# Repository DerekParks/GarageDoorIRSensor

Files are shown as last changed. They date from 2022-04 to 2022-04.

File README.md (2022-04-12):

# Garage Door IR Sensor

This is a little garage door state sensor based on Sharp IR sensors, an ADS1115, & an ESP-01. I originally planned to hack this together with parts I had around in an afternoon. Two months later, here were are. 😉 

The boards were made for a CT clamp current sensor but work great for reading in any voltage from 0-3.3v.

 A schematic is below. The IR sensors hook up to ports 3  & 4 of the ADS1115.
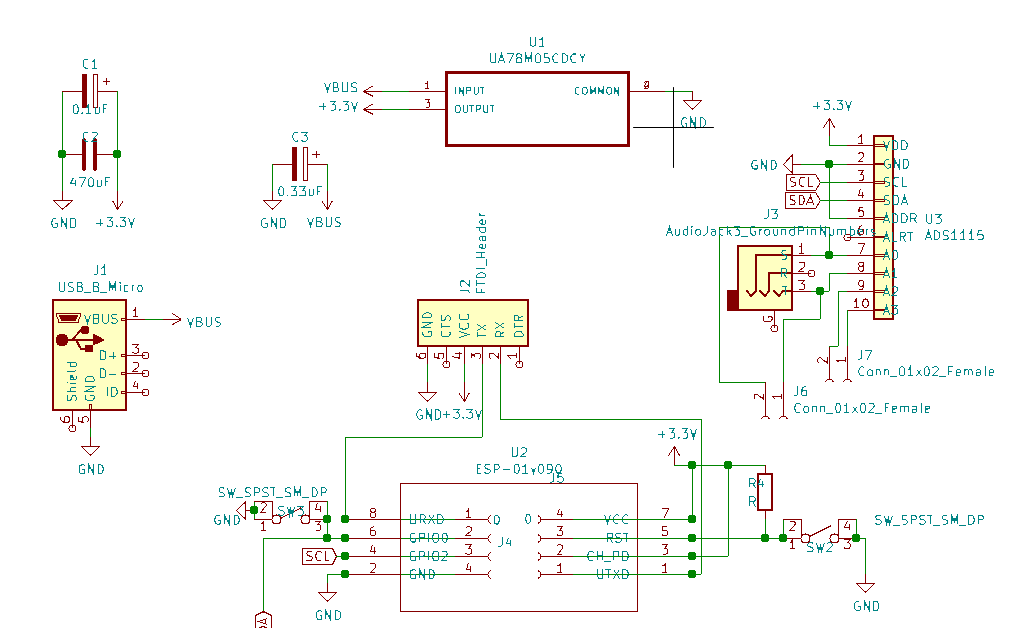
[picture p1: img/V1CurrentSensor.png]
Schematic


The IR sensors need to be placed between the garage door rail and the wall (see pictures below). When the door is down, the sensors should read around 1.5 volts and near-zero when the door is up.

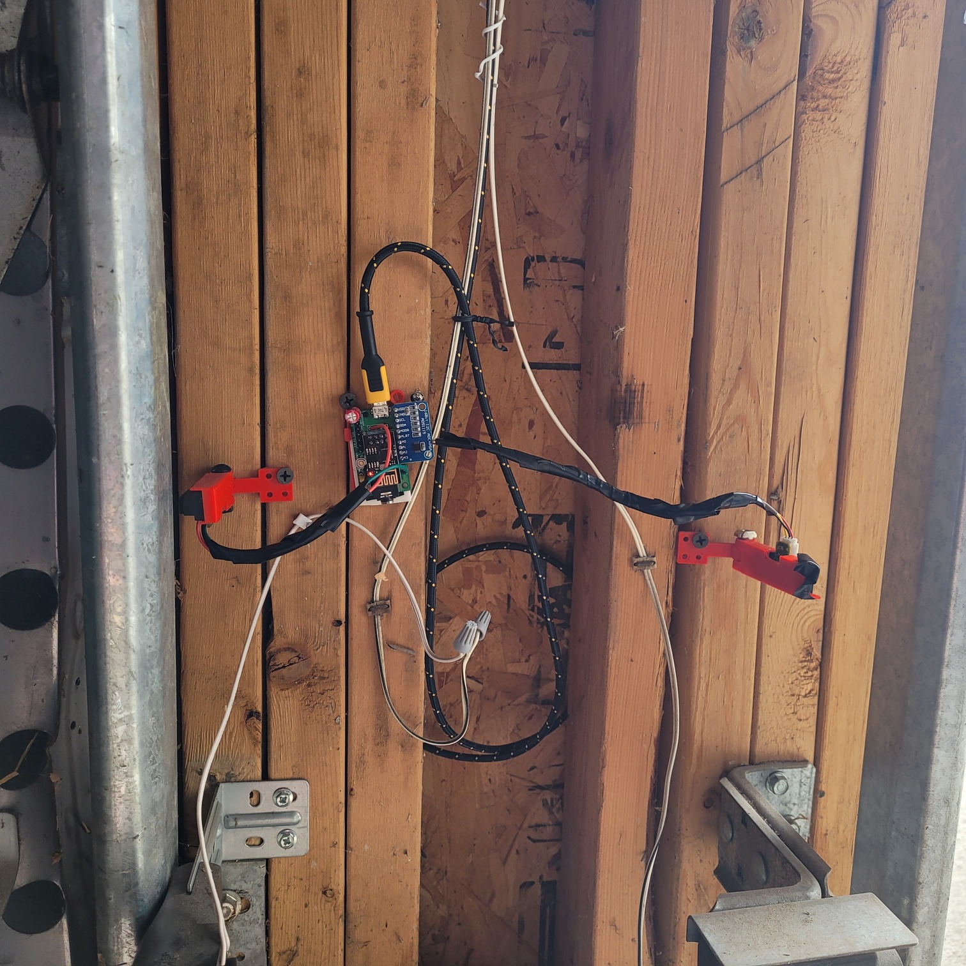
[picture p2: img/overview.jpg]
Overview


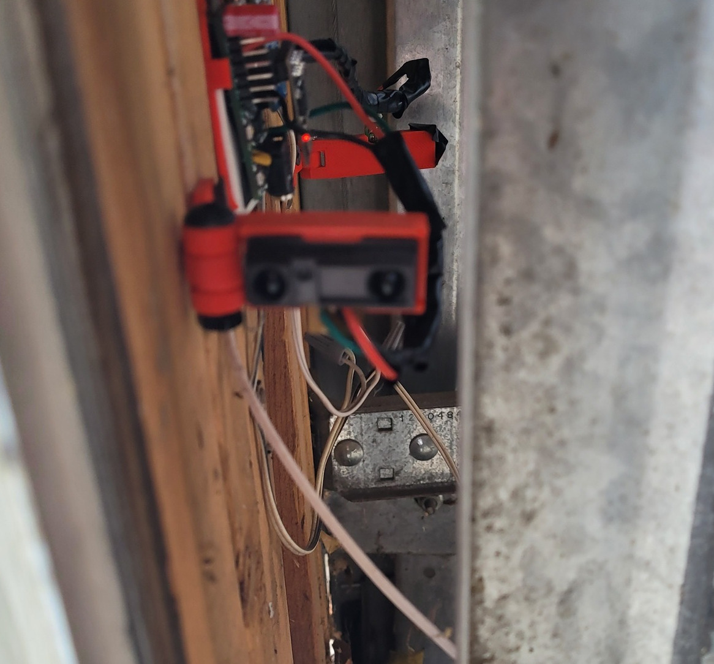
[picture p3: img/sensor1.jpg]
Looking in at sensor with door up

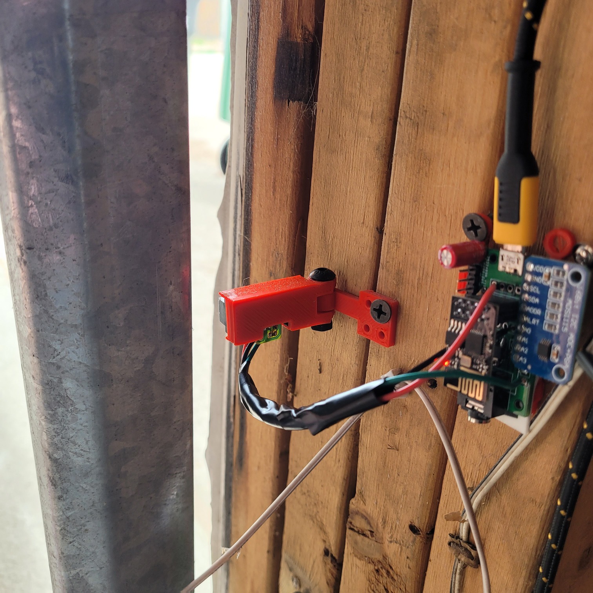
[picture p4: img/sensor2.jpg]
Looking out at door with door up

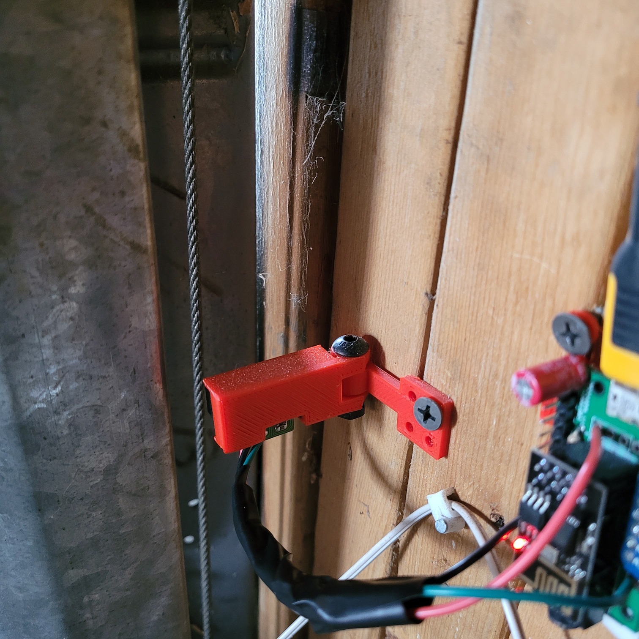
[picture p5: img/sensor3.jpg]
Looking out at door with door closed


## Home assistant 

There are examples for creating MQTT covers &  notifications working with home assistant in the `ha` directory.

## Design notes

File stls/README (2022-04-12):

On Tinker cad at:
 https://www.tinkercad.com/things/dUf3icjU5Bx

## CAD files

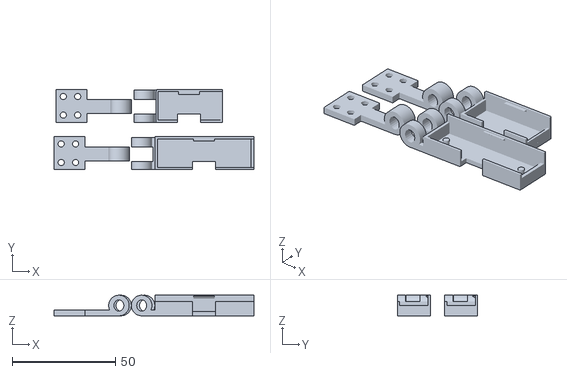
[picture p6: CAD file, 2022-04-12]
stls/IR Sensor.stl
97.0 x 39.0 x 10.0

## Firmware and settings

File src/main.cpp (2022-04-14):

#include <Arduino.h>
#include <Adafruit_ADS1X15.h>
#include "ExpFilter.h"
#include <ESP8266WiFi.h>
#include <ESPAsyncTCP.h>
#include <ESPAsyncWebServer.h>

#include <MQTT.h>
#include "topics.h"

#define OPEN_DOOR_ALERT 600000            // Send message to alert topic after 10 min
#define MOVING_DOOR_MILLS 6000            // How long does it take the door to open/close
#define FORCE_REFRESH_EVERY_MILLS 600000  // How often should we refresh mqtt (useful if we don't want to deal with mqtt retain but still want to get state updated after an HA reboot)
#define CUT_OFF_VOLTAGE 0.9               // What voltage from the IR sensor should be the cuttoff between open and closed


// WebSerial can be useful for in situ debuging 

//#define USE_WEBSERIAL false

#ifdef USE_WEBSERIAL

#include <WebSerial.h>
#define S WebSerial

AsyncWebServer server(80);

#else

#define S Serial

#endif

// MQTT setup
WiFiClient net;
MQTTClient client(500);

// Turn defines into strings
#define XSTR(x) #x
#define STR(x) XSTR(x)

// Wifi & MQTT creds are read in through build flags. See platofrmio.ini. Print them out when building
#pragma message STR(DP_WIFI_SSID)
#pragma message STR(DP_WIFI_PASS)
#pragma message STR(DP_MQTT_HOST)
#pragma message STR(DP_MQTT_USER)
#pragma message STR(DP_MQTT_PASS)

// Wifi & MQTT creds
const char* ssid = STR(DP_WIFI_SSID);
const char* password = STR(DP_WIFI_PASS);

const char* mqtt_host = STR(DP_MQTT_HOST);
const char* mqtt_user = STR(DP_MQTT_USER);
const char* mqtt_pass = STR(DP_MQTT_PASS);

#define EXP_FILTER_TAU 3000 // Millis decay for exponential filter  

Adafruit_ADS1115 ads;
ExpFilter filter3(EXP_FILTER_TAU);
ExpFilter filter2(EXP_FILTER_TAU);

unsigned long tLast, tNext;      // temp times
unsigned long tLastStateChange1; // last time state 1 changed
unsigned long tLastStateChange2; // last time state 2 changed
unsigned long tLastAvilUpdate;   // last time MQTT was updated
unsigned long tLastAlertUpdate1 = 0; // last time we alerted on state 1
unsigned long tLastAlertUpdate2 = 0; // last time we alerted on state 2

// Temp variables
int16_t adc3;
float volts3, filtered3;

int16_t adc2;
float volts2, filtered2;

// Use to limit logging a bit
int16_t measureCount = 0;

// Possible door states
enum DoorState {closed, opening, open, closing};

// Assume closed to start but shouldn't matter
DoorState s1 = closed;
DoorState s2 = closed;


// Convert state to char*
inline const char* toString(DoorState state)
{
    switch (state)
    {
        case closed:   return "closed";
        case opening:  return "opening";
        case open:     return "open";
        case closing:  return "closing";
        default:       return "[Unknown state]";
    }
}

// Reconnect to MQTT
void connect() {
  S.print("checking wifi...");
  while (WiFi.status() != WL_CONNECTED) {
    S.print(".");
    delay(1000);
  }

  S.print("\nconnecting...");
  while (!client.connect(STR(MQTT_CLIENT), mqtt_user, mqtt_pass)) {
    Serial.print(".");
    delay(1000);
  }

  S.println("\nconnected!");
}

// Handle possible state change if we have a high voltage
DoorState high_voltage(
  unsigned long tCurrent, 
  unsigned long tLastStateChange,
  DoorState s
  ) {
  switch(s) {
      case closed: return closed;
      case opening:
      case open:
        return closing;
      case closing:
        if((tCurrent - tLastStateChange) > MOVING_DOOR_MILLS) {
          return closed;
        } else {
          return closing;
        }
  }
  return s;
}

// Handle possible state change if we have a low voltage
DoorState low_voltage(
  unsigned long tCurrent, 
  unsigned long tLastStateChange,
  DoorState s
) {
  switch(s) {
      case open: return open;
      case closing:
      case closed:
        return opening;
      case opening:
        if((tCurrent - tLastStateChange) > MOVING_DOOR_MILLS) {
          return open;
        } else {
          return opening;
        }
  }
  return s;
}

void setup() {
  Serial.begin(115200);
  Serial.println("Booting");

  //WIFI setup
  WiFi.mode(WIFI_STA);
  WiFi.begin(ssid, password);

  while (WiFi.waitForConnectResult() != WL_CONNECTED) {
    Serial.println("Connection Failed! Rebooting...");
    delay(5000);
    ESP.restart();
  }

  Serial.println("Ready");
  Serial.print("IP address: ");
  Serial.println(WiFi.localIP());

  //MQTT setup
  client.begin(mqtt_host, net);
  connect();

#ifdef USE_WEBSERIAL
  WebSerialPro.begin(&server);
  server.begin();
#else
  
#endif

  // Say we are Offline until we have meassure state
  client.publish(STR(AVIL_TOPIC1), "Offline");
  client.publish(STR(AVIL_TOPIC2), "Offline");

  // Setup ADC
  Wire.begin(0, 2);
  delay(10);
  if (!ads.begin()) {
    Serial.println("Failed to initialize ADS.");
    while (1000);
  }
  
  tLast = millis();

  //Tell MQTT we are up and running and current state
  client.publish(STR(AVIL_TOPIC1), "Online");
  client.publish(STR(AVIL_TOPIC2), "Online");

  tLastAvilUpdate = tLast;
  client.publish(STR(STATE_TOPIC1), toString(s1));
  client.publish(STR(STATE_TOPIC2), toString(s2));
}

void loop() {
  client.loop(); // mqtt stay connected

  //Read voltages from ADC
  adc3 = ads.readADC_SingleEnded(3);  // ADC port 3 is connected to state 1
  volts3 = ads.computeVolts(adc3);

  adc2 = ads.readADC_SingleEnded(2);  // ADC port 2 is connected to state 2
  volts2 = ads.computeVolts(adc2);

  tNext = millis(); 

  unsigned long dt = (tNext > tLast) ? tNext - tLast : tLast - tNext; // Find time since last update

  // Exp filter voltages
  filtered3 = filter3.add(volts3, dt);  
  filtered2 = filter2.add(volts2, dt);

  if (measureCount == 100) {

    if (!client.connected()) {
      connect();
    }

    // Check for state 1 changes
    DoorState s1New = s1;
    if (filtered3 <= CUT_OFF_VOLTAGE) {
      s1New = low_voltage(tNext, tLastStateChange1, s1);
    } else {
      s1New = high_voltage(tNext, tLastStateChange1, s1);
    }
    
    // Handle state 1 changes
    if(s1 != s1New) {
      s1 = s1New;
      tLastStateChange1 = tNext;
      tLastAlertUpdate1 = tNext;
      client.publish(STR(STATE_TOPIC1), toString(s1));
      S.print("Changing state:"); S.println(toString(s1));
    }

    // Check for state 2 changes
    DoorState s2New = s2;
    if (filtered2 <= CUT_OFF_VOLTAGE) {
      s2New = low_voltage(tNext, tLastStateChange2, s2);
    } else {
      s2New = high_voltage(tNext, tLastStateChange2, s2);
    }
    
    // Handle state 2 changes
    if(s2 != s2New) {
      s2 = s2New;
      tLastStateChange2 = tNext;
      tLastAlertUpdate2 = tNext;
      client.publish(STR(STATE_TOPIC2), toString(s2));
      S.print("Changing state2:"); S.println(toString(s2));
    }

    // Check if we need to alert because state 1 is open for too long
    if(s1 == open && (tNext - tLastAlertUpdate1) > OPEN_DOOR_ALERT) {
      client.publish(STR(ALERT_TOPIC1), toString(s1));
      tLastAlertUpdate1 = tNext;
      S.print("Alert1:"); S.println(toString(s1));
    }

    // Check if we need to alert because state 2 is open for too long
    if(s2 == open && (tNext - tLastAlertUpdate2) > OPEN_DOOR_ALERT) {
      client.publish(STR(ALERT_TOPIC2), toString(s2));
      tLastAlertUpdate2 = tNext;
      S.print("Alert2:"); S.println(toString(s2));
    }

    // Logging
    S.print("AIN3: "); S.print(adc3); S.print("  "); S.print(volts3); 
    S.print("V "); S.print(filtered3); S.println("V"); 

    S.print("AIN2: "); S.print(adc2); S.print("  "); S.print(volts2); 
    S.print("V "); S.print(filtered2); S.println("V"); 

    // Check if refresh is needed
    if((tNext - tLastAvilUpdate) > FORCE_REFRESH_EVERY_MILLS) {
      client.publish(STR(AVIL_TOPIC1), "Online");
      client.publish(STR(AVIL_TOPIC2), "Online");
      client.publish(STR(STATE_TOPIC1), toString(s1));
      client.publish(STR(STATE_TOPIC2), toString(s2));

      tLastAvilUpdate = tNext;
    }

    measureCount = 0;
  }

  tLast = tNext;
  measureCount++;
}

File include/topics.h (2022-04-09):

#define AVIL_TOPIC1 home/garageNorth/avail
#define STATE_TOPIC1 home/garageNorth/state
#define ALERT_TOPIC1 home/garageNorth/alert

#define AVIL_TOPIC2 home/garageSouth/avail
#define STATE_TOPIC2 home/garageSouth/state
#define ALERT_TOPIC2 home/garageSouth/alert

#define MQTT_CLIENT garage_door_esp

// Auto discover is not well documented. I wasted a lot of time on it. Giving up for now.
//#define CONFIG_TOPIC homeassistant/cover/garageNorth/config
//constexpr char const* MQTT_AUTO_DISC = "{\"name\":\"Garage Door North\", \"unique_id\": \"garageNorth\", \"state_topic\":\"homeassistant/cover/garageNorth/state\",\"availability\":{\"topic\":\"homeassistant/cover/garageNorth/availability\"},\"payload_available\":\"Online\",\"payload_not_available\":\"Offline\",\"state_opening\":\"opening\",\"state_closing\":\"closing\",\"state_open\":\"open\",\"state_closed\":\"closed\"}";

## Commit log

2022-04-12 Add images
    [IR Sensor.stl]
2022-04-14 Use latest esptool; typos; and switch off of WebSerialPro for public
